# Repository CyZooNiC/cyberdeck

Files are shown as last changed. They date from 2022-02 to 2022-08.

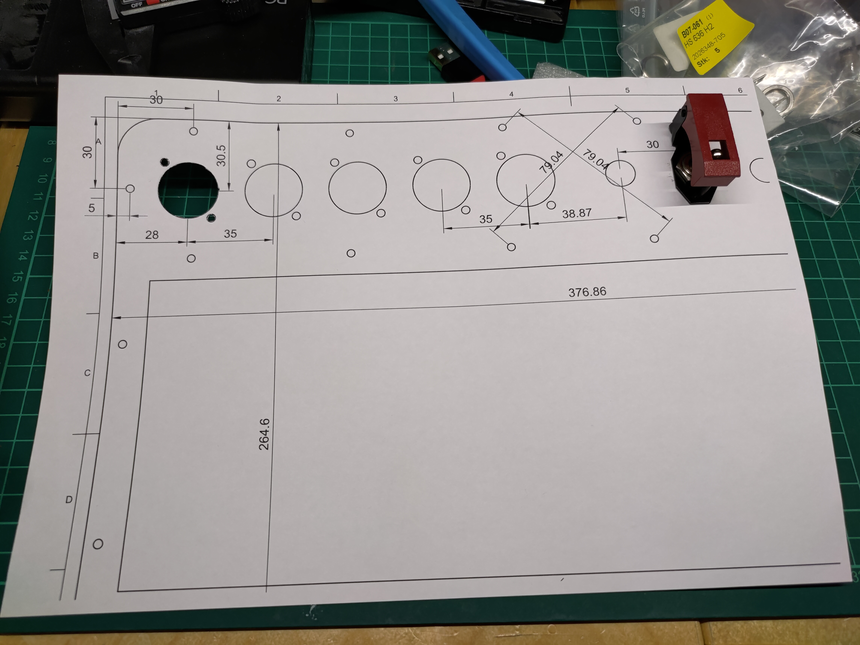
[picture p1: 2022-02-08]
photos/P_20210519_131817_-_Copy.jpg

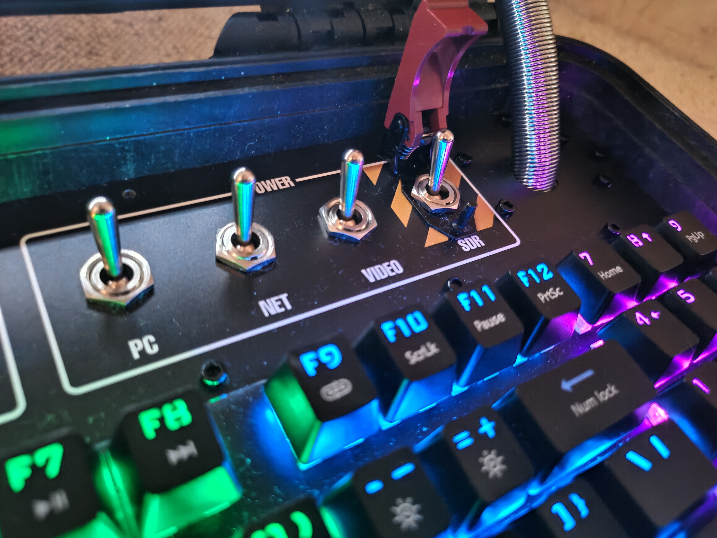
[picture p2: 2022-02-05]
photos/P_20220129_155057.jpg

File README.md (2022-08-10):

# Cyberdeck

### 3D Models
 - Lid Plate
 - Base Plate
 - Umbilical Guide
 - Case brackets

### PCB
- SDR Controller

### Services used
 - https://blexon.com/ (Metal work)
 - https://www.tenstickers.ch/ (Stickers)

### BOM
 - Pelican case, PELI 1450 black https://www.brack.ch/peli-schutzkoffer-1450-schwarz-360008
 - Raspberry Pi 3B https://rpilocator.com/?cat=PI3
 - Toggle Switches https://secure.reichelt.com/ch/en/lever-switch-to-10-a-1x-on-on-hs-636-h2-p105645.html
 - Toggle Switch guard https://secure.reichelt.com/ch/en/safety-covers-red-schutz-20-26-p105664.html
 - INA226 Voltage Current Monitor https://www.aliexpress.com/item/1005003463006131.html
 - SD extension: https://www.aliexpress.com/item/1005001928805506.html
 - LED mount https://www.aliexpress.com/item/1005002248561990.html
 - ESP32 https://www.aliexpress.com/item/4000093420330.html
 - power connector: https://www.aliexpress.com/item/32872816780.html
 - charger: https://www.aliexpress.com/item/1005001638456602.html
 - keypad: https://www.aliexpress.com/item/4000873237364.html
 - black screws https://www.aliexpress.com/item/1005001711625966.html
 - 3S2 Battery BMS https://www.aliexpress.com/item/4000648416374.html
 - HDMI cables between top and bottom https://www.aliexpress.com/item/4001090468470.html
 - Batteries https://www.aliexpress.com/item/32324914059.html
 - USB audio https://www.aliexpress.com/item/33056020608.html
 - USB hub https://www.aliexpress.com/item/4000292920801.html
 - SMA extnesion https://www.aliexpress.com/item/4000245307369.html
 - Knobs https://www.aliexpress.com/item/32608693397.html
 - Step down modules https://www.aliexpress.com/item/32706909050.html
 - Rotary encoder https://www.aliexpress.com/item/32873198060.html
 - DIN clips https://www.aliexpress.com/item/1005001834824551.html
 - DIN bridge https://www.aliexpress.com/item/1005001834788898.html
 - OLED display https://www.aliexpress.com/item/33027484504.html
 - Pannel buttons https://www.aliexpress.com/item/1005001732343587.html
 - gigabit switch https://www.aliexpress.com/item/32991083909.html
 - RTL SDR https://www.aliexpress.com/item/1005001271827620.html
 - DIN rail https://www.aliexpress.com/item/4000126680453.html
 - jack dust covers https://www.aliexpress.com/item/4000484462480.html
 - pannel ports https://www.aliexpress.com/item/4000102342780.html
 - LCD 11.6 -https://www.aliexpress.com/item/4001050343035.html
 - keyboard https://www.aliexpress.com/item/4001224586963.html
 - water proof USB https://www.aliexpress.com/item/32902706764.html
 - water proof network https://www.aliexpress.com/item/32856098897.html
 - Umbilical 180mm https://www.aliexpress.com/item/1005001568585310.html

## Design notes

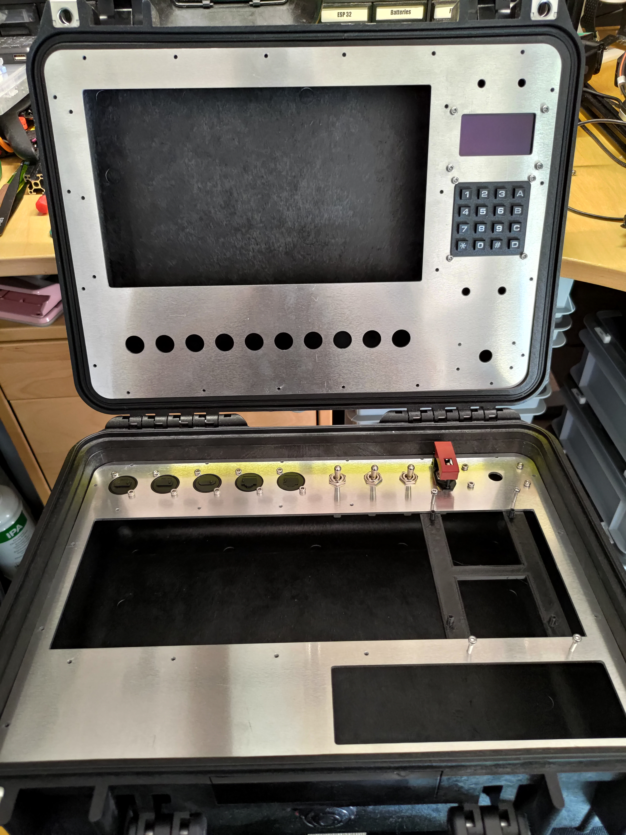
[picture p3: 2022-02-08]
photos/P_20210528_174531_-_Copy.jpg

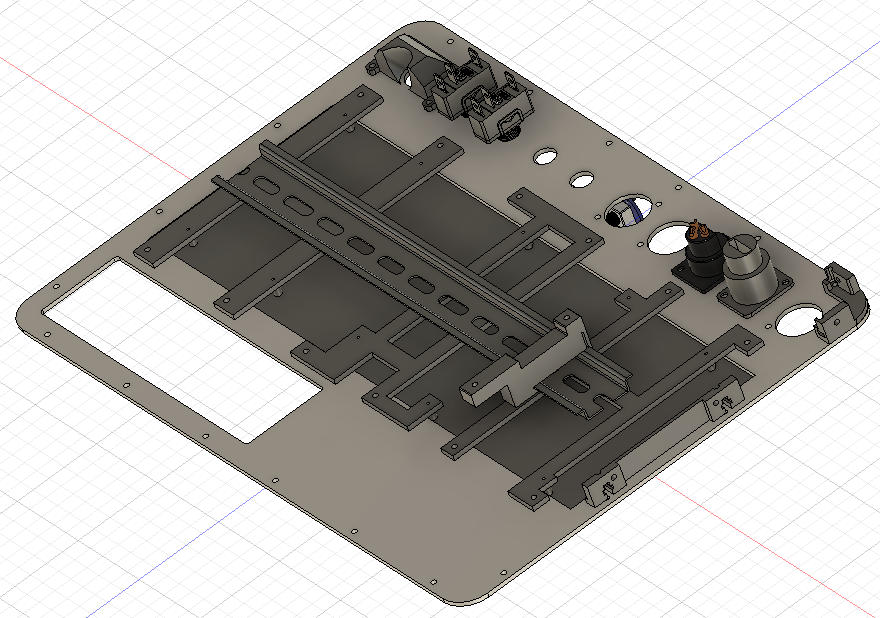
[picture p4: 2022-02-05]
photos/Screenshot_2022-01-31_12-58-51.png

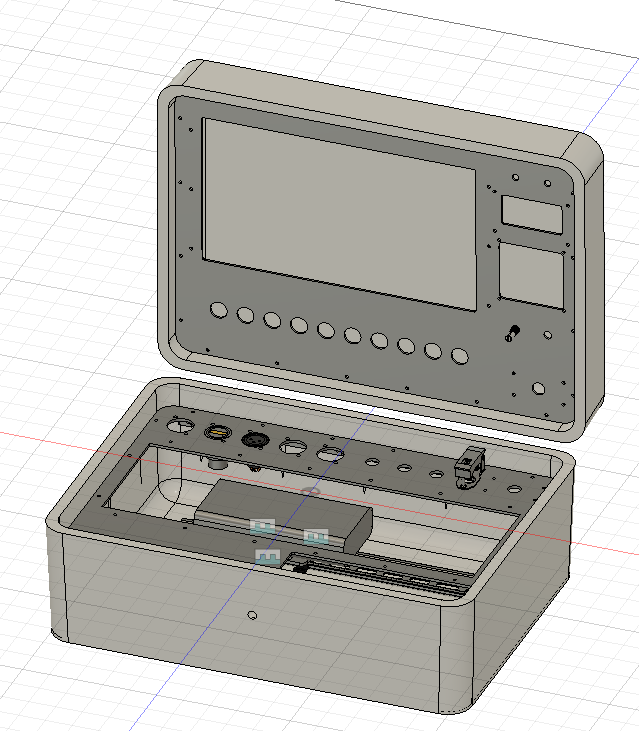
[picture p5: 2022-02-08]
photos/CropperCapture424.png

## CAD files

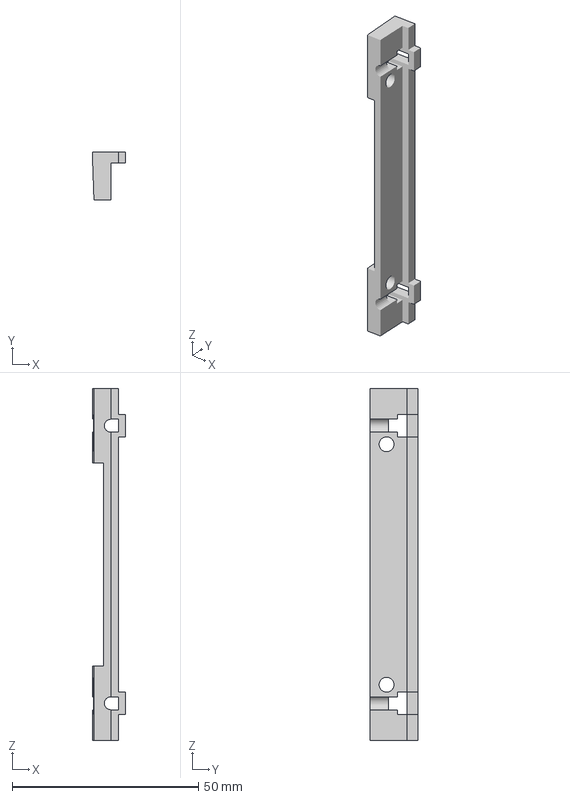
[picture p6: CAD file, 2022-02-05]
3dmodels/mount-long.3mf
9.00 x 13.0 x 94.6 mm

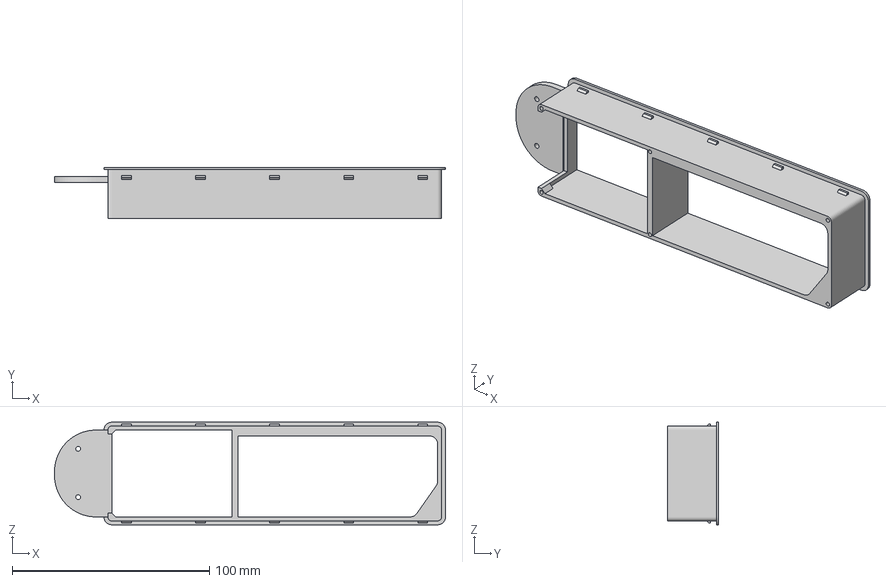
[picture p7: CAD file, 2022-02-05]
3dmodels/storage_tray_side.3mf
198.0 x 26.0 x 52.0 mm

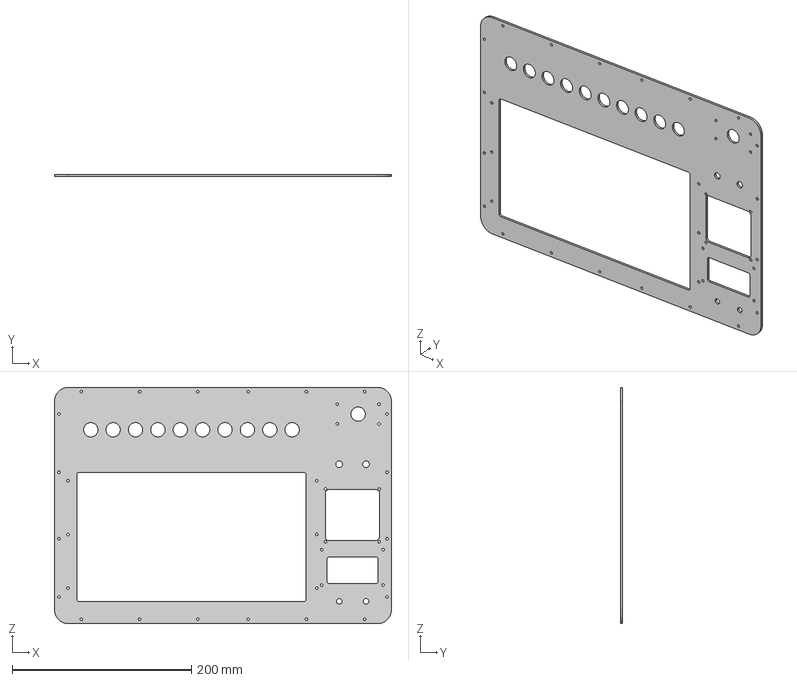
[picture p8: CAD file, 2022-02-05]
3dmodels/TopLid.step
376.5 x 2.50 x 264.2 mm

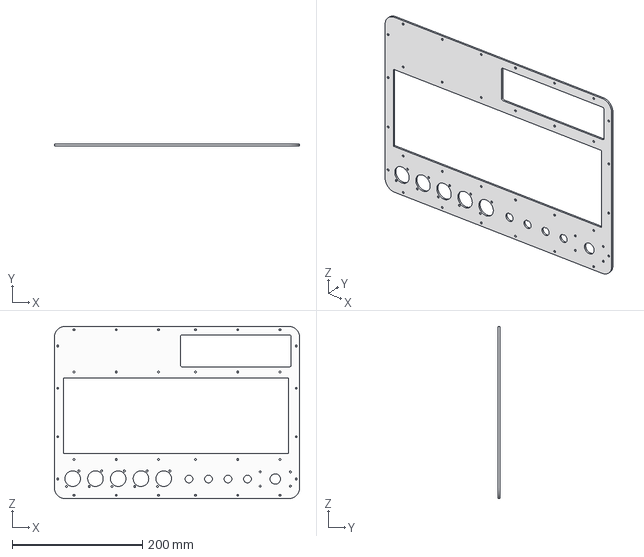
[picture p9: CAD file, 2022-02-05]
3dmodels/BottomLid.3mf
376.9 x 2.50 x 264.6 mm

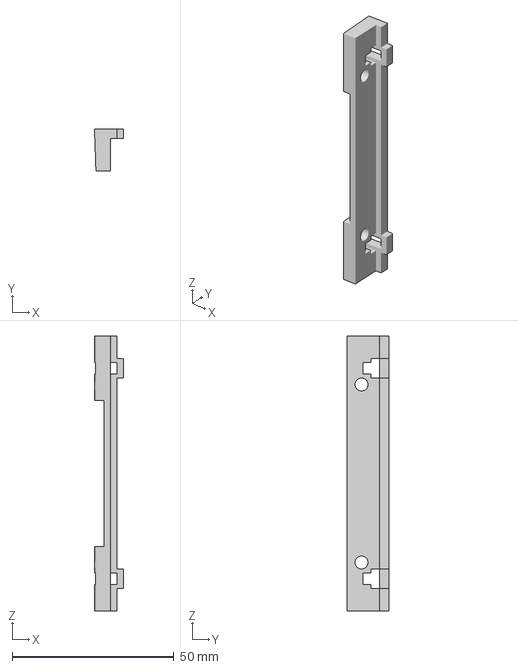
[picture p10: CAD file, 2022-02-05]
3dmodels/mount-short.3mf
9.00 x 13.0 x 85.0 mm

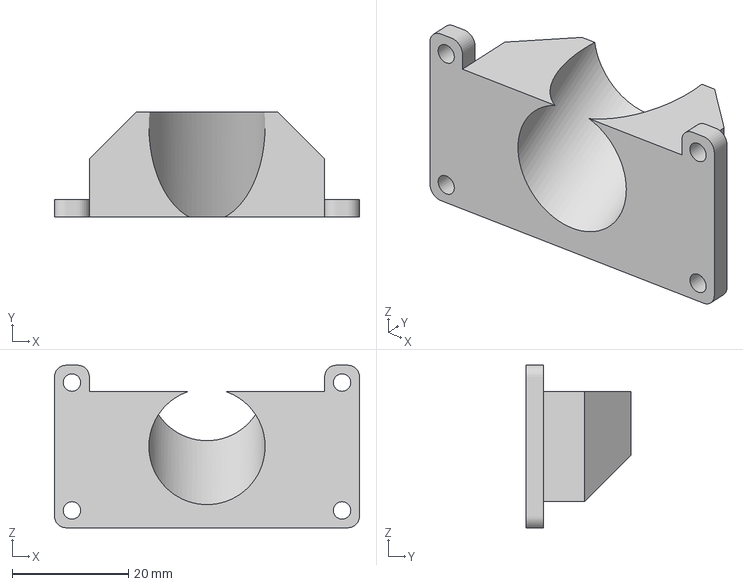
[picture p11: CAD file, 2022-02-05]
3dmodels/Umbilical_guide.3mf
52.5 x 18.0 x 28.0 mm

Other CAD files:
3dmodels/storage_tray_bottom.3mf
3dmodels/BottomLid v11.step
3dmodels/storage_tray.step
3dmodels/TopLid.3mf

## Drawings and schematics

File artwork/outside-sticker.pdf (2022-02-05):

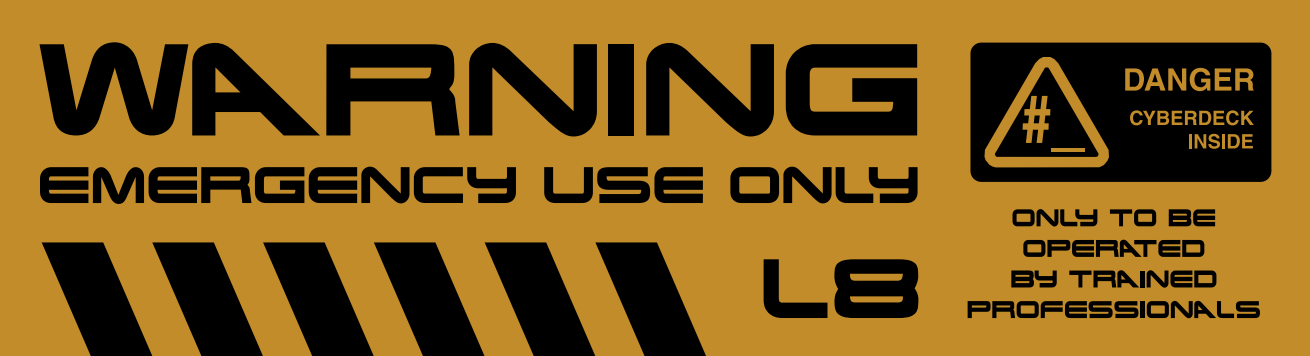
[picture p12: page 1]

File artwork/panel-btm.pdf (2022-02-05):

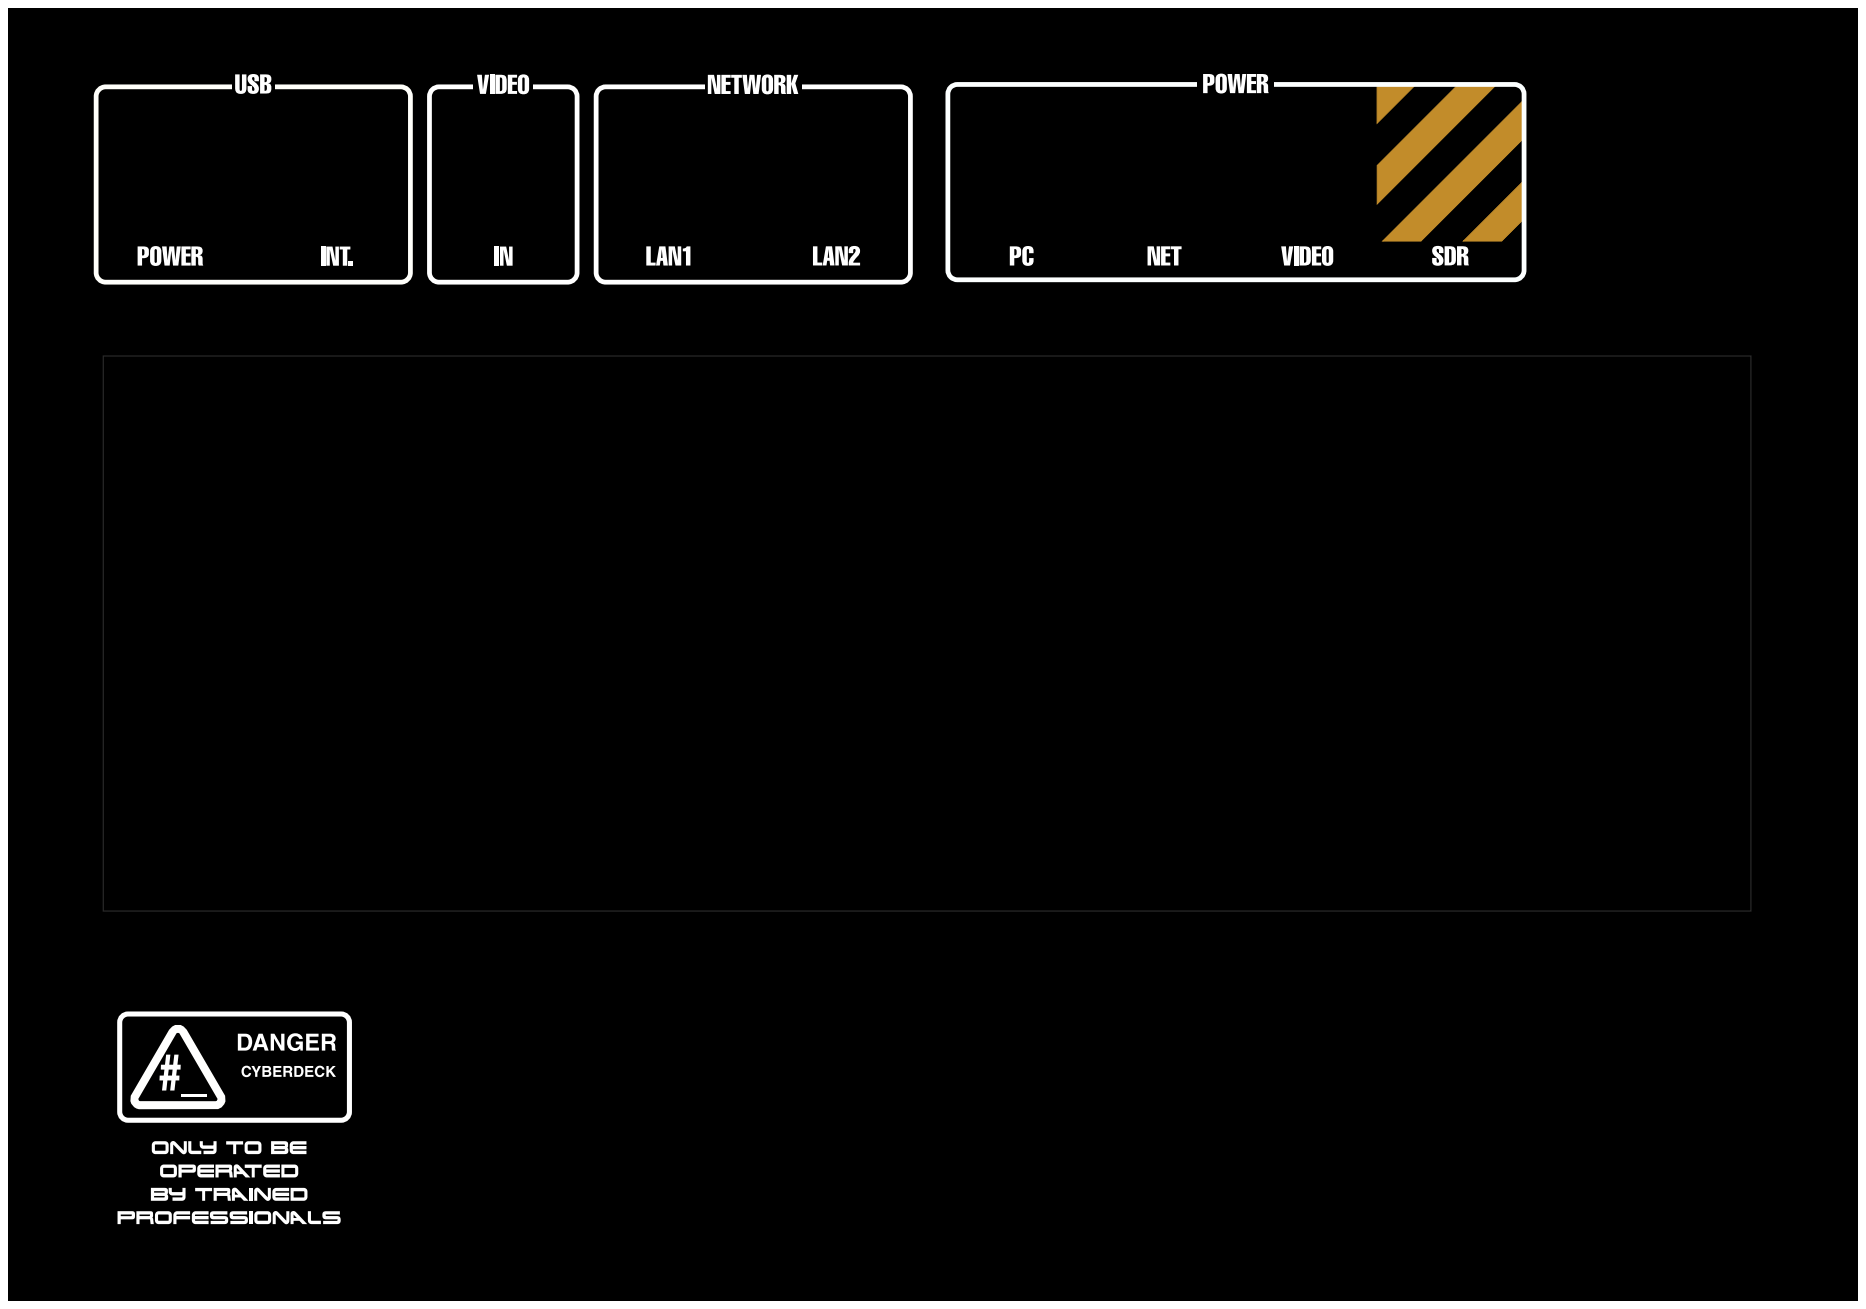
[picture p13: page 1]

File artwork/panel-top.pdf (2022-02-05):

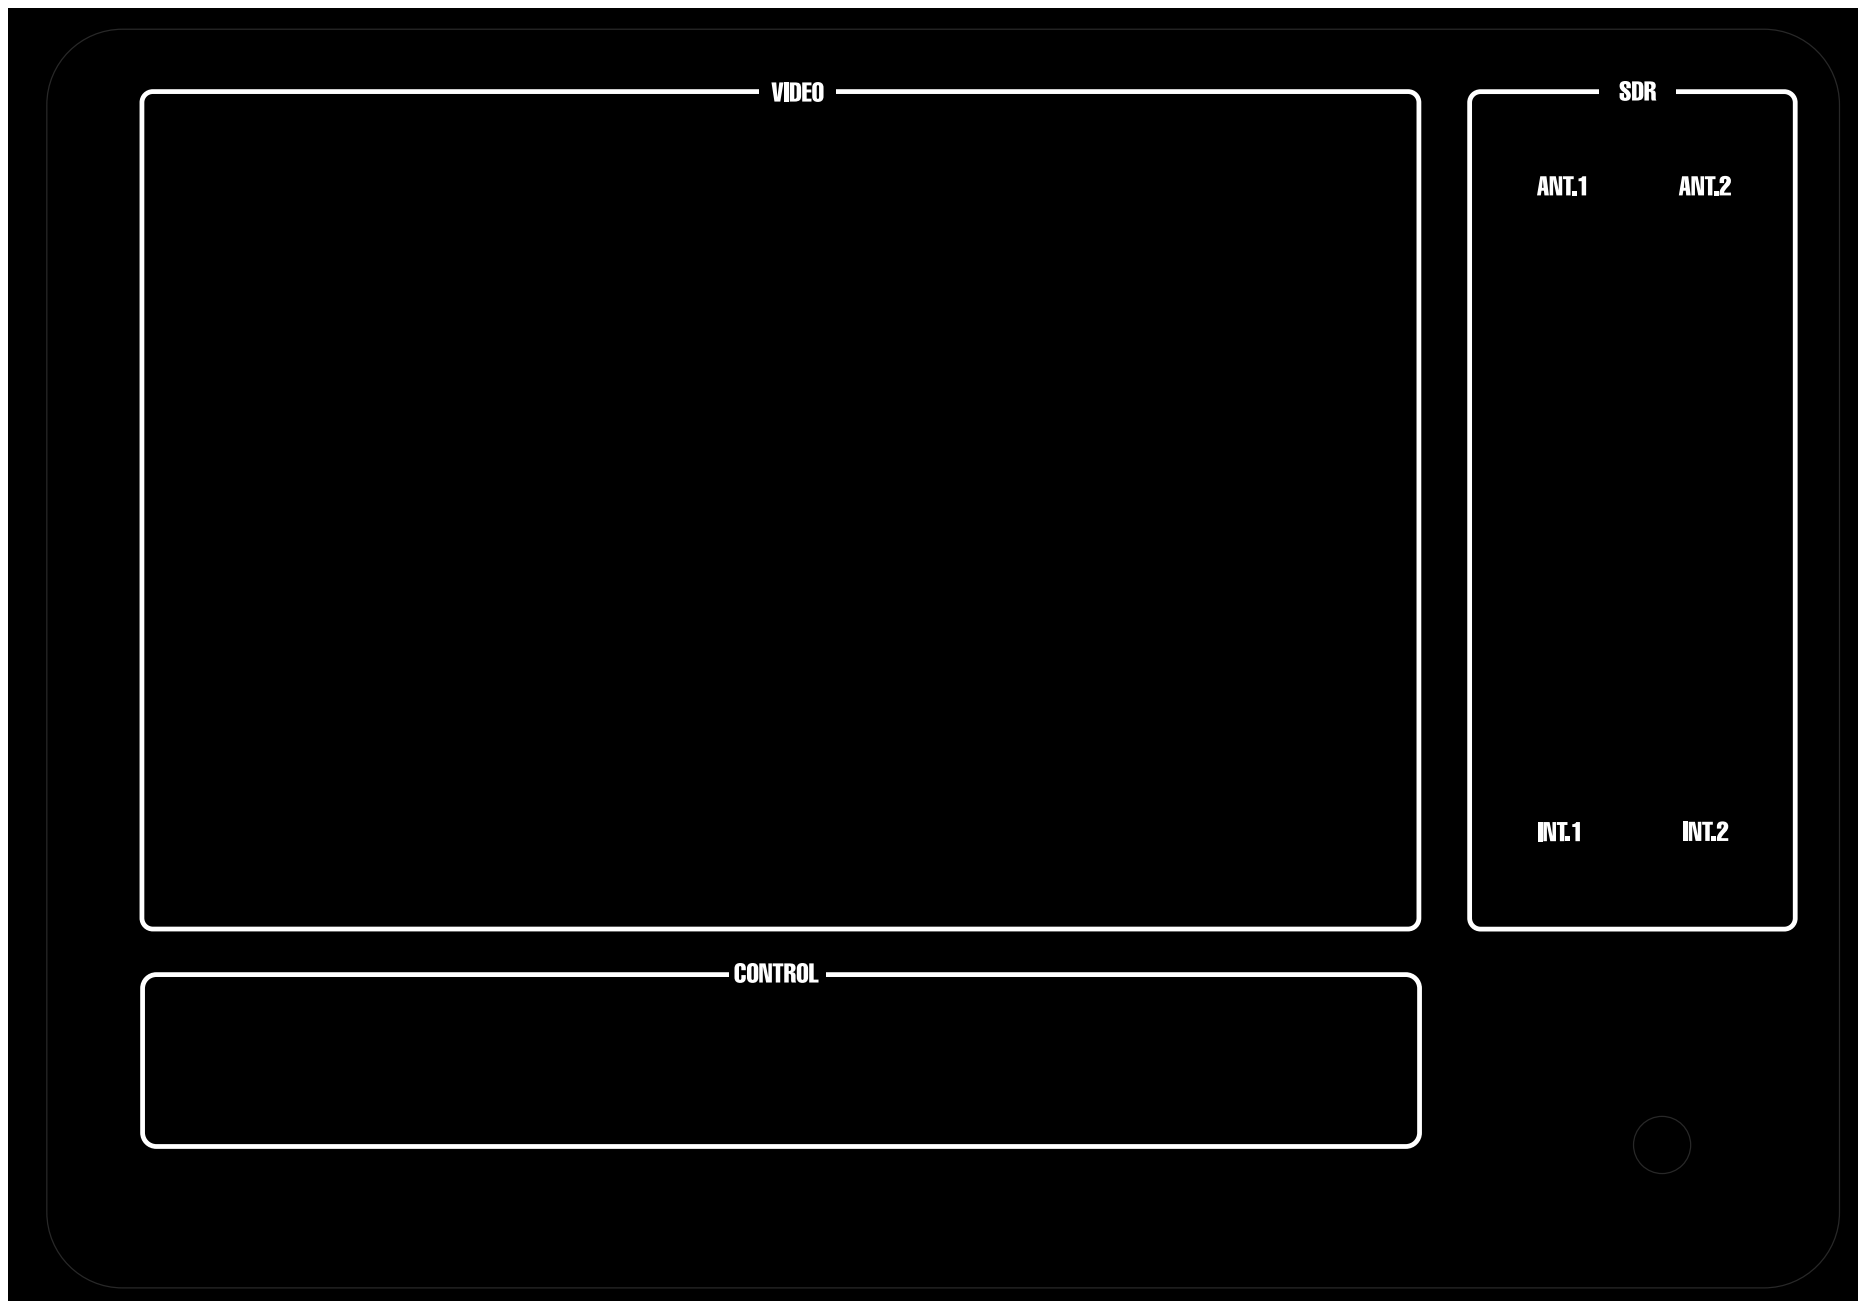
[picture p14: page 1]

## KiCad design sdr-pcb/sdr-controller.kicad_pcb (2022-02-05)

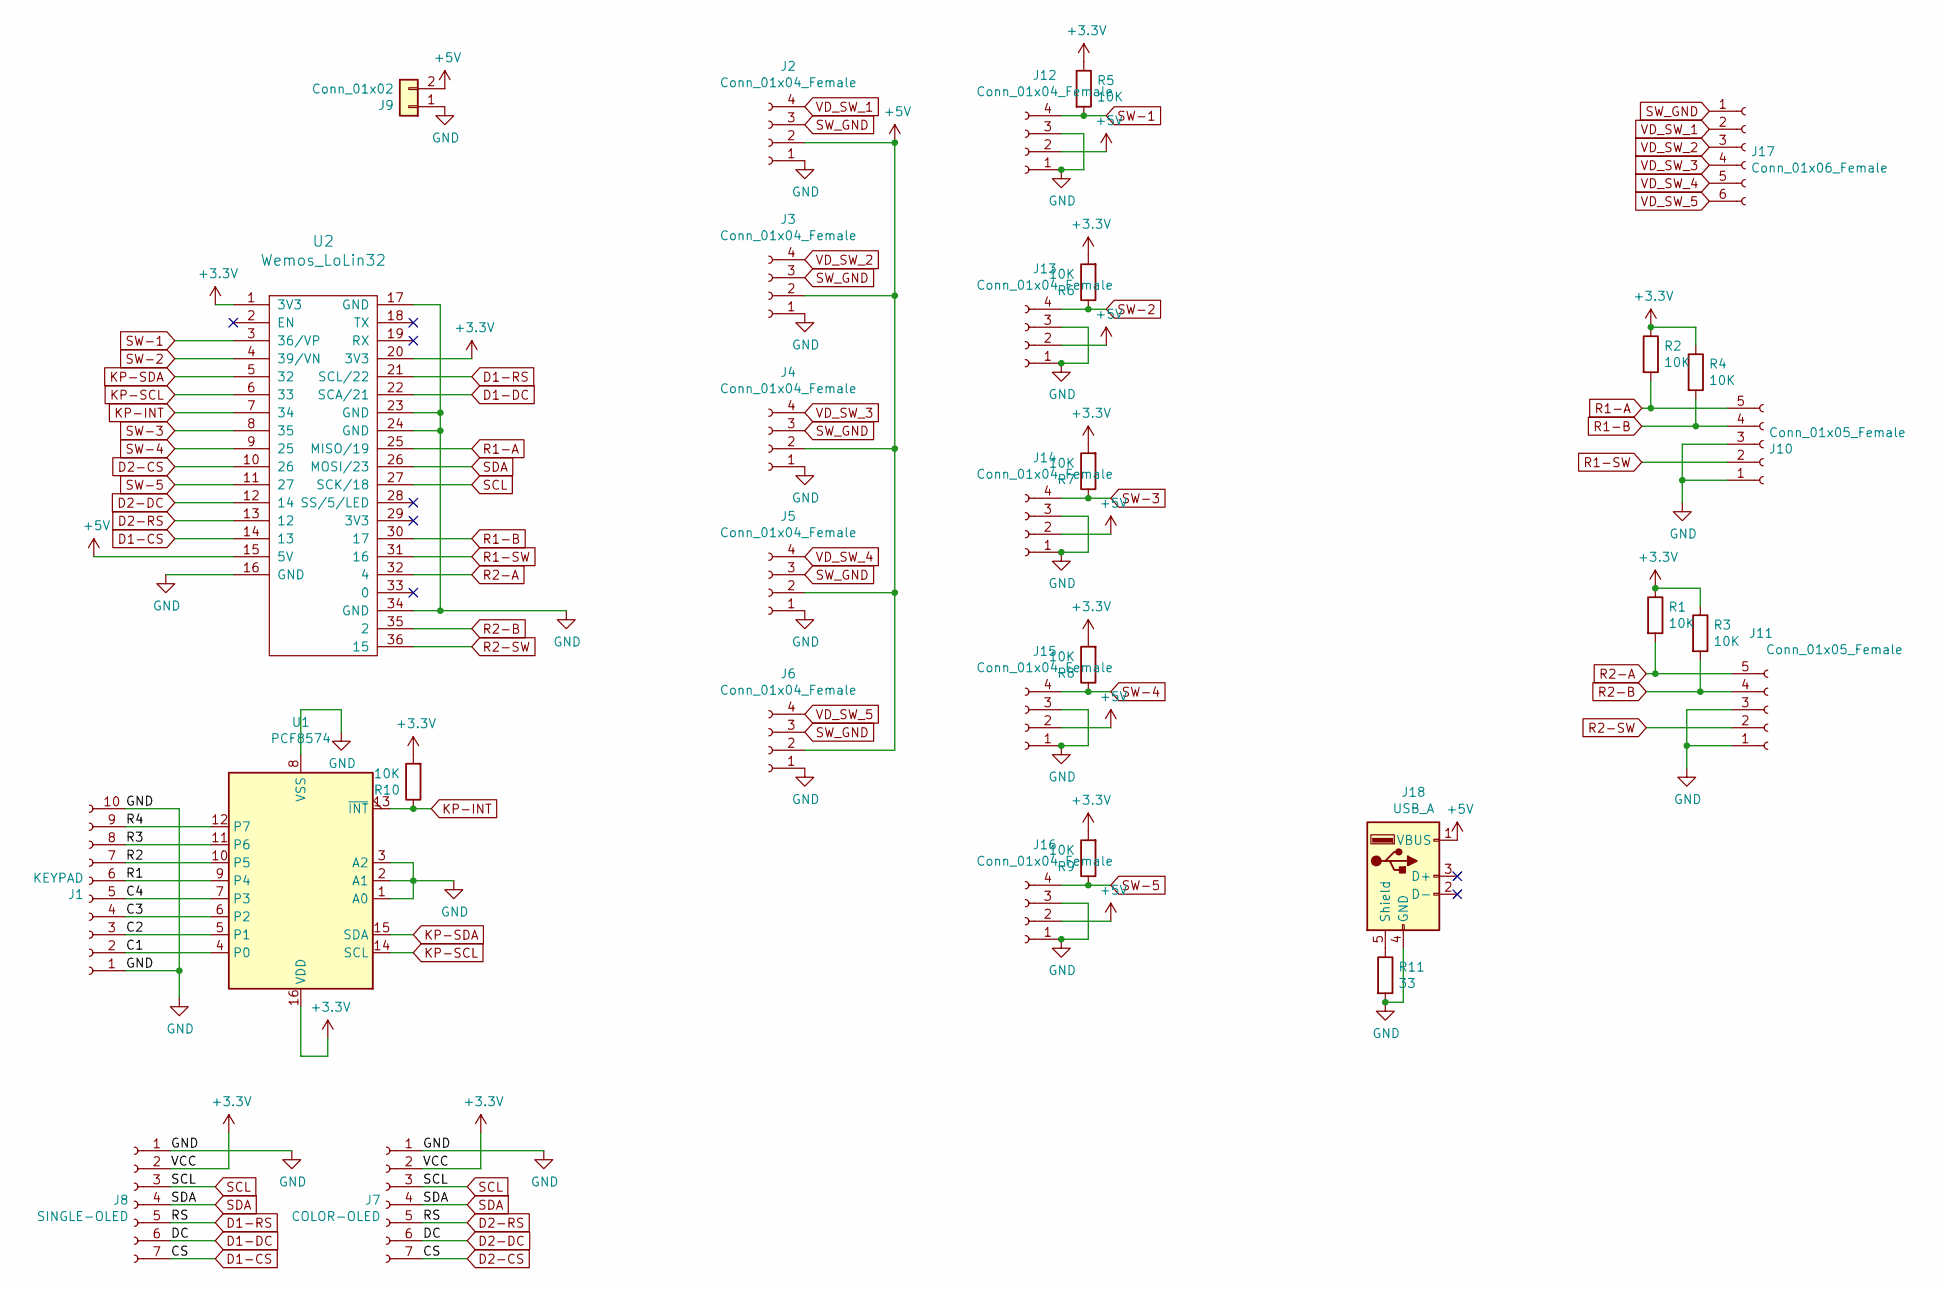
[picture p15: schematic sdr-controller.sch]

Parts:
J1: KEYPAD; Pin_Header_Straight_1x10_Pitch2.54mm
J2, J3, J4, J5, J6, J12, J13, J14, J15, J16: Conn_01x04_Female; Molex_KK-6410-04_04x2.54mm_Straight
J7: COLOR-OLED; Molex_KK-6410-07_07x2.54mm_Straight
J8: SINGLE-OLED; Molex_KK-6410-07_07x2.54mm_Straight
J9: Conn_01x02; Molex_KK-6410-02_02x2.54mm_Straight
J10, J11: Conn_01x05_Female; Molex_KK-6410-05_05x2.54mm_Straight
J17: Conn_01x06_Female; Molex_KK-6410-06_06x2.54mm_Straight
J18: USB_A; USB-Module-Micro
R1, R2, R3, R4, R5, R6, R7, R8, R9, R10: 10K; 1206
R11: 33; 1206
U1: PCF8574; DIP-16_W7.62mm
U2: Wemos_LoLin32; LoLin_32_Board

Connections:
+3V3: J7.2, J8.2, R1.1, R2.1, R3.1, R4.1, R5.1, R6.2, R7.2, R8.2, R9.2, R10.2, U1.16 (VDD), U2.1 (3V3), U2.20 (3V3)
+5V: J2.2, J3.2, J4.2, J5.2, J6.2, J9.2, J12.2, J13.2, J14.2, J15.2, J16.2, J18.1 (VBUS), U2.15 (5V)
/C1: J1.2, U1.4 (P0)
/C2: J1.3, U1.5 (P1)
/C3: J1.4, U1.6 (P2)
/C4: J1.5, U1.7 (P3)
/R1: J1.6, U1.9 (P4)
/R2: J1.7, U1.10 (P5)
/R3: J1.8, U1.11 (P6)
/R4: J1.9, U1.12 (P7)
D1-CS: J7.7, J8.7, U2.10 (26), U2.14 (13)
D1-DC: J7.6, J8.6, U2.12 (14), U2.22 (SCA/21)
D1-RS: J7.5, J8.5, U2.13 (12), U2.21 (SCL/22)
GND: J1.1, J1.10, J2.1, J3.1, J4.1, J5.1, J6.1, J7.1, J8.1, J9.1, J10.1, J10.3, J11.1, J11.3, J12.1, J12.3, J13.1, J13.3, J14.1, J14.3, J15.1, J15.3, J16.1, J16.3, J18.4 (GND), R11.2, U1.1 (A0), U1.2 (A1), U1.3 (A2), U1.8 (VSS), U2.16 (GND), U2.17 (GND), U2.23 (GND), U2.24 (GND), U2.34 (GND)
KP-INT: R10.1, U1.13 (~INT~), U2.7 (34)
KP-SCL: U1.14 (SCL), U2.6 (33)
KP-SDA: U1.15 (SDA), U2.5 (32)
unnamed: J18.5 (Shield), R11.1
R1-A: J10.5, R2.2, U2.25 (MISO/19)
R1-B: J10.4, R4.2, U2.30 (17)
R1-SW: J10.2, U2.31 (16)
R2-A: J11.5, R1.2, U2.32 (4)
R2-B: J11.4, R3.2, U2.35 (2)
R2-SW: J11.2, U2.36 (15)
SCL: J7.3, J8.3, U2.27 (SCK/18)
SDA: J7.4, J8.4, U2.26 (MOSI/23)
SW-1: J12.4, R5.2, U2.3 (36/VP)
SW-2: J13.4, R6.1, U2.4 (39/VN)
SW-3: J14.4, R7.1, U2.8 (35)
SW-4: J15.4, R8.1, U2.9 (25)
SW-5: J16.4, R9.1, U2.11 (27)
SW_GND: J2.3, J3.3, J4.3, J5.3, J6.3, J17.1
VD_SW_1: J2.4, J17.2
VD_SW_2: J3.4, J17.3
VD_SW_3: J4.4, J17.4
VD_SW_4: J5.4, J17.5
VD_SW_5: J6.4, J17.6

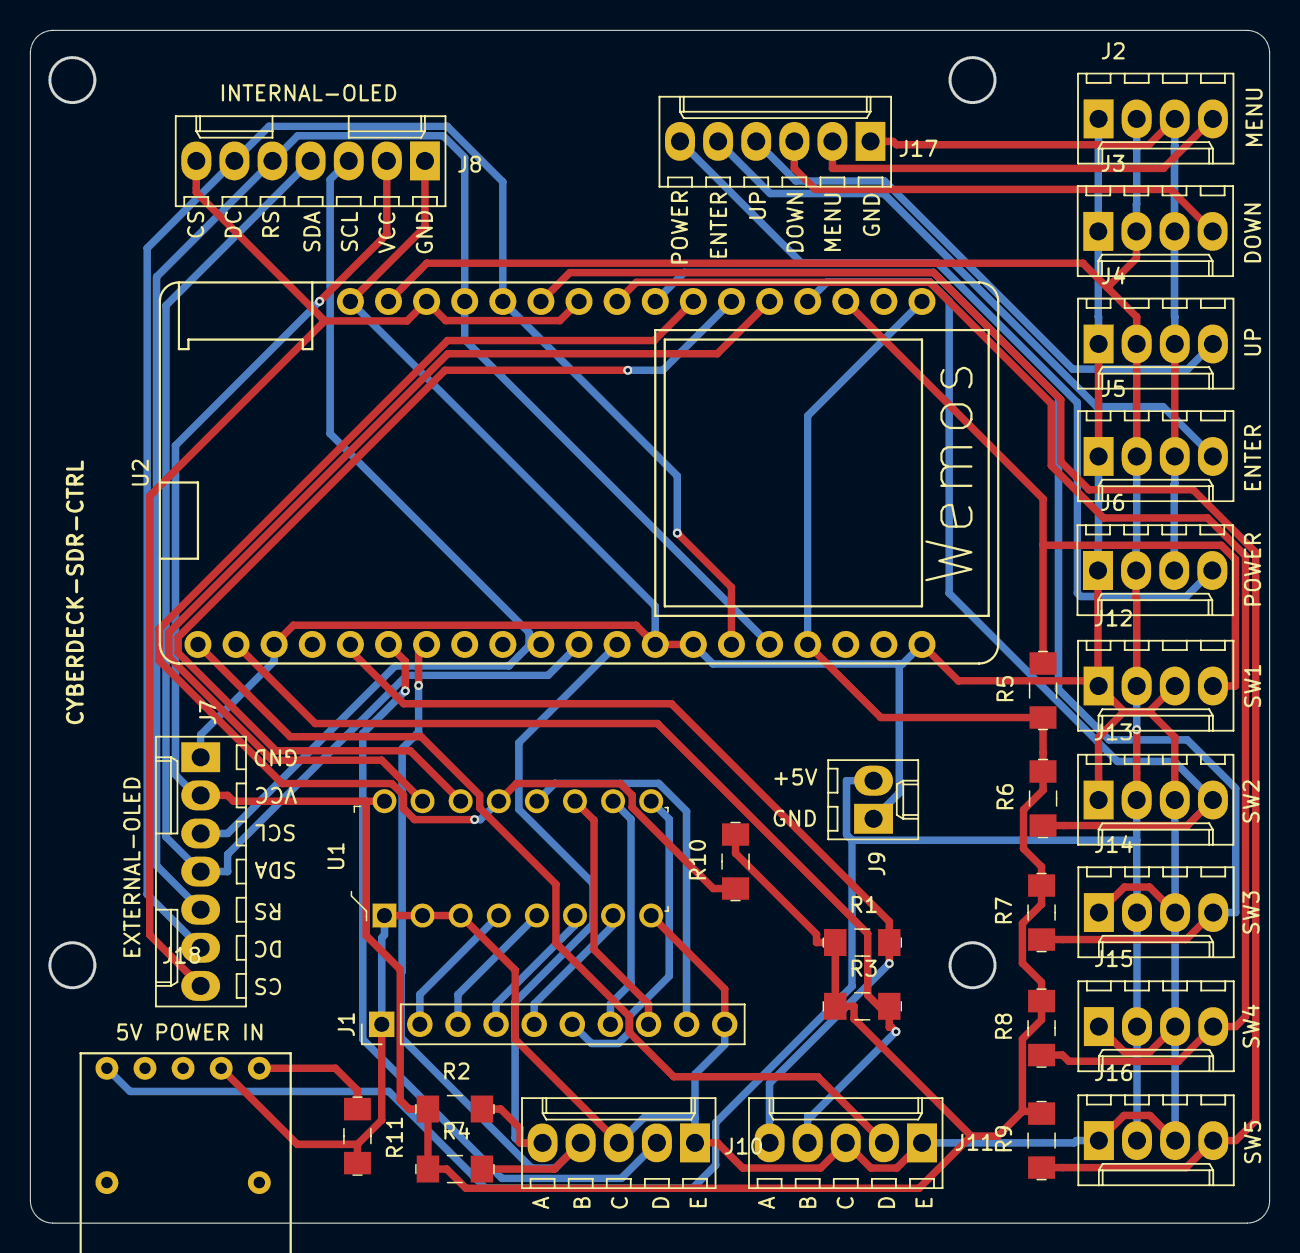
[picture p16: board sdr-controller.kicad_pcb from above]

Board: 2 copper layers, 82.6 x 79.5 mm, 31 parts (0 on the bottom side), 37 nets.

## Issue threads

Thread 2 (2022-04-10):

Sdr

Hunterleeb, 2022-04-10:
Was wondering if you could link what sdr you used?

sschueller, 2022-04-10:
I am currently using this one: https://www.aliexpress.com/item/1005001271827620.html and I have used this one as well: https://www.aliexpress.com/item/32936334224.html

I am considering getting a HackRF One eventually.

Hunterleeb, 2022-04-10:
Awsome man thank you so much! I really appreciate it. Are all of those 3d
models on your github everything I’ll need as far as the aluminum plates,
storage bin and the 3d printed brackets?

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

sschueller, 2022-04-10:
Currently missing from the github is the 3d printed keyboard mounting brackets which are a bit of a mess.I will try to sort those out and get them online as well. I have also not finished the software for the esp32 so that is currently not online either.

Also checkout the cyberdeck cafe on discord: https://discord.gg/HVDMKGrR

Hunterleeb, 2022-04-10:
Perfect thank you I was gonna say I couldn’t find anything on those parts
on there! Is there any way I could pay you to print me the 3d parts you
used assuming you own a 3d printer? It would just be easier on my end to
not have to deal with sending the files to someone to have it done but
completely get it if your too busy or unable to do that. Again really
appreciate the response and I just joined the discord!

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

sschueller, 2022-04-10:
Sadly at the moment none of my 3d printers are operational and I currently don't know when I have to time to get them running again (highly depends on what project I work on next which I don't know right now).

I would recommend just getting one like a Creality Ender 3 (under USD 200) or if you have the money a Prusia 3d printer. I would not recommend getting a SLA printer for this as the parts needs to be somewhat strong and if you don't plan on printing small models SLA printers are just messy. Alternatively you can go to a local maker space where you can rent them. The parts are all printed in PETG which is more resilient than PLA but almost as easy to print.

Hunterleeb, 2023-12-26:
Hey man was curious if you’d be interested in selling you cyber deck?

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

Closed 2023-12-30.

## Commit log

2022-02-05 3d models
    [Ambilical_guide.3mf, BottomLid v11.step, BottomLid.3mf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]
2022-02-05 PCB photos
2022-03-13 mv 3dmodels/Ambilical_guide 3dmodels/Umbilical_guide
    [Umbilical_guide.3mf]
2022-08-10 Update README.md
    Added html cables
